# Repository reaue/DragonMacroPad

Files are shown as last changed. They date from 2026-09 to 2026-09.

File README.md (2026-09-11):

# DragonMacroPad

A macro pad with 8 switches, one rotary encoder, one OLED display and of course some RGB. It uses [QMK](https://qmk.fm/) firmware.

# CAD model

The full case and the pcb are connected by four M3x13mm screws and M3x5mx4mm heatset inserts, the inserts come under the `Top_case` and your screw the all macro pad by the bottom of the `Bottom_case`, like a sandwich with the pcb in the middle.

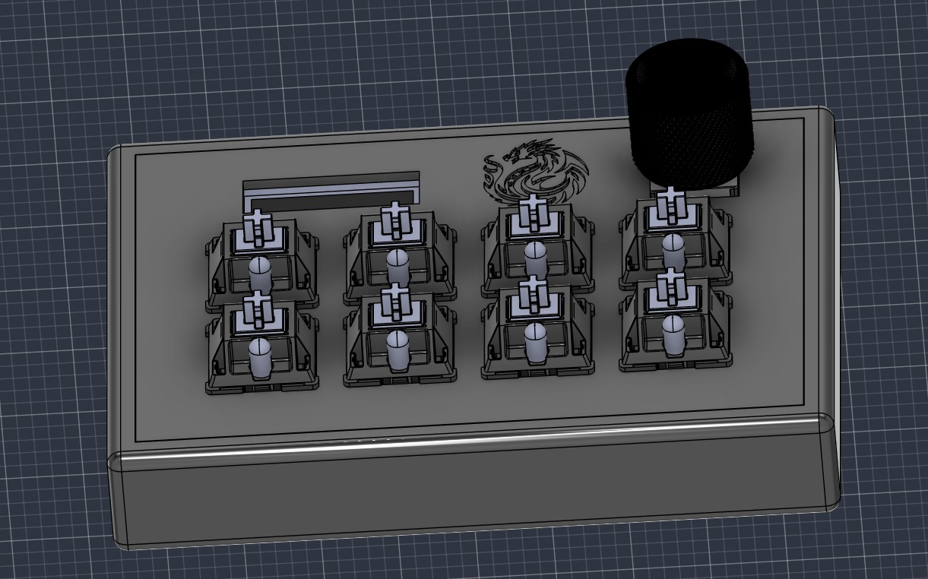
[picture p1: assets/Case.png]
Case


# Case parts

### Top_case

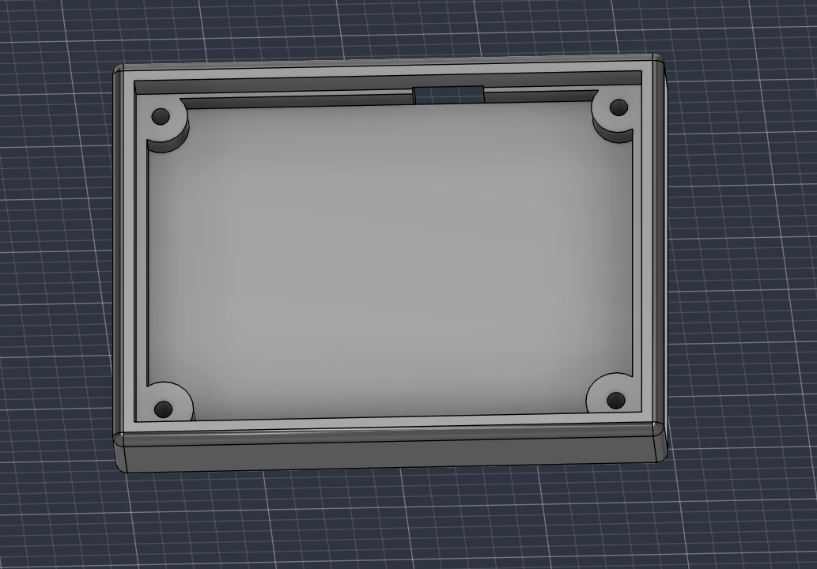
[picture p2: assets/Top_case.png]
Top_case


### Bottom_case

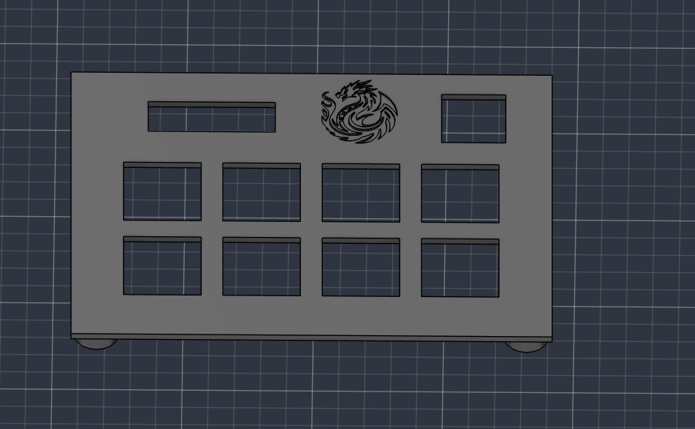
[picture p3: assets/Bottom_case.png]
Bottom_case


# PCB

### Schematic

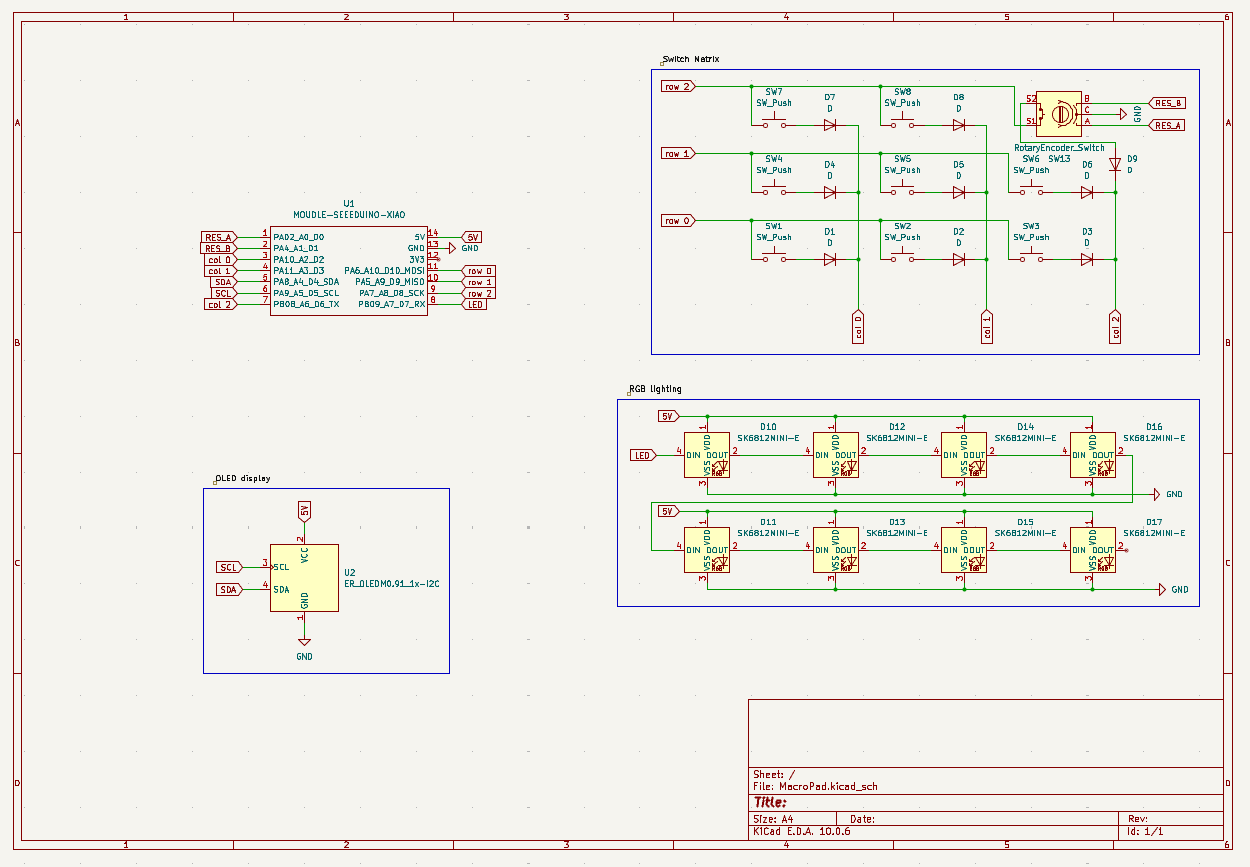
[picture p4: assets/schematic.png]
schematic


### PCB

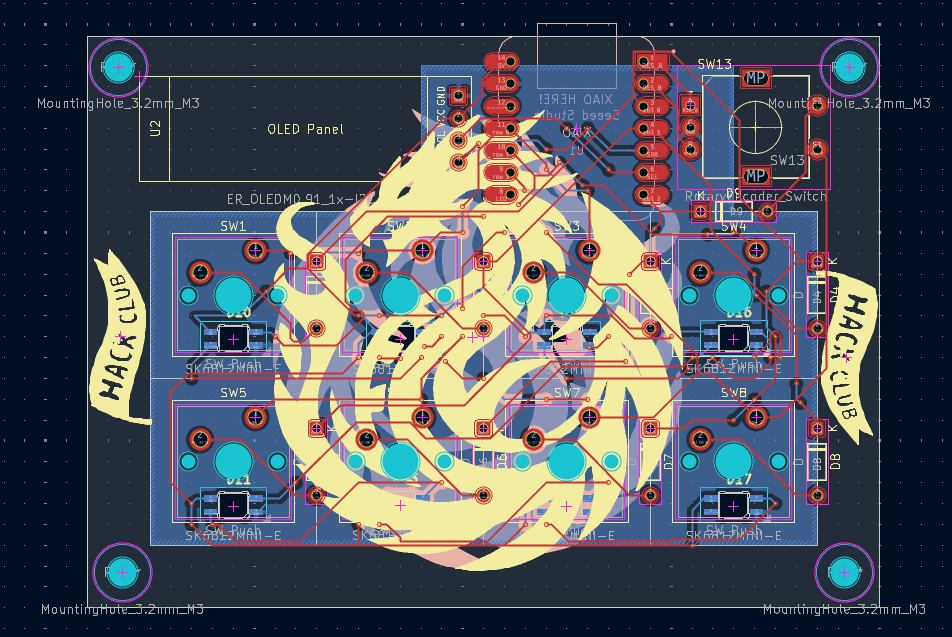
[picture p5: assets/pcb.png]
pcb


### The 3D model

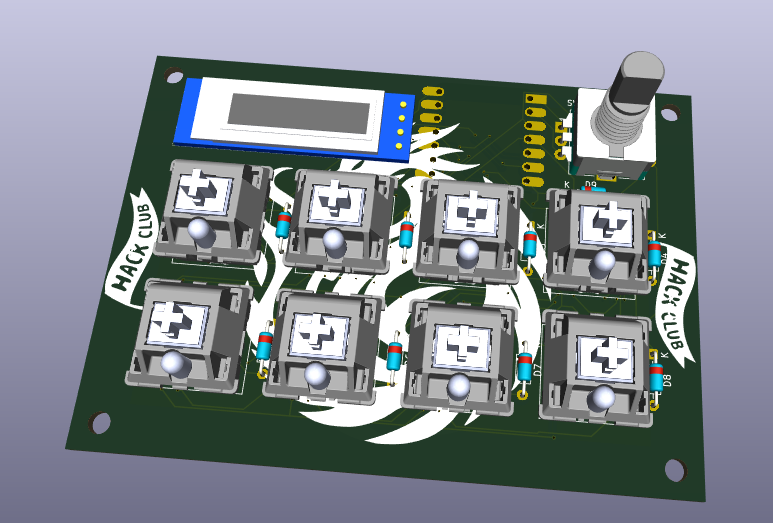
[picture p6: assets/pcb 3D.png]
PCB 3D


# Firmware

I use QMK for this DragonMacroPad.

Here, keys binding (in order, starting from the top right) :
- RGB Toggle
- RGB Mode Switch
- Previous Track
- Next Track
- Copy
- Paste
- Undo
- Redo

- The rotary encoder changes Volume and if it's press switch between Play/Pause.

# BOM

The real one is in the repo.

| Component | Quantity |
|---|---:|
| XIAO RP2040 | 1 |
| Cherry MX Switches | 8 |
| EC11 Rotary Encoder | 1 |
| WS2812 RGB LED | 8 |
| 0.91" 128x32 OLED Display | 1 |
| 1N4148 DO-35 Diodes | 9 |
| DSA Keycaps | 8 |
| PCB | 1 |
| M3x13mm | 4 |
| M3 M3x5x4 Heatset inserts | 4 |
| Case (2 printed parts )| 1 |
| EC11 Knob ( printed part )| 1 |

# Possible improvement

Take switches which are Led SMD compatible (such as Gateron SMD Yellow), because Cherry MX Switches do not let pass so much light.

# Credits

I used [QMK](https://qmk.fm/) and [Kicad](https://www.kicad.org/).
Moreover, I used one 3D model from [Ziemniaczenka](https://www.printables.com/@Ziemniaczenka)

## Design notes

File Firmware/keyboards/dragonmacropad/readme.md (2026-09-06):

# Firmware

**QMK**: This is a QMK firmware port of the dragonmacropad.

The firmware includes support for the 3×3 key matrix, rotary encoder, RGB LEDs and OLED display.

The compiled `.uf2` file is also included and ready to flash.

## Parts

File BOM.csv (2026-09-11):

Item name | Qty | Price (USD) | Item link | Note
XIAO RP2040 | 1 | 3.90 | https://www.seeedstudio.com/XIAO-RP2040-v1-0-p-5026.html
Cherry MX Switches | 8 | 21.99 | https://cherryxtrfy.com/keyboard-switches/cherry-mx-honey-switches/
EC Rotary Encoder | 1 | 1.61 | https://simbay.de/product/encoder-with-push-button/
WS2812 RGB Led | 8 | 0.90 | https://electropeak.com/ws2812b-5050-rgb-milky-smd
0.91 128x32 OLED Display | 1 | 2.90 | 0.91 128x32 OLED Display
1N4148 DO-35 Diodes | 9 | 0.94 | www.digikey.be/fr/products/detail/onsemi/1N4148/458603
DSA Keycaps | 8 | 6.85 | https://shop.beekeeb.com/products/dsa-1u-keycaps?variant=45012851425587&country=AT&currency=EUR
PCB printing | 1 | 4.00 | https://cart.jlcpcb.com/quote?stencilLayer=2&stencilWidth=100&stencilLength=100&stencilCounts=5&plateType=1
M3x13mm | 4 | 1.30 | https://eu.store.bambulab.com/fr/products/m3-flat-head-cap-machine-screws-fhcs?id=48691726909788&skr=yes
M3 M3x5x4 Heatset inserts | 4 | 6.25 | https://nl.aliexpress.com/item/4000232858343.html?gatewayAdapt=usa2nld4itemAdapt
Case (2 printed parts ) | 1 | 5.42 | https://www.prusa3d.com/fr/p/prusa-center/calculator
EC11 Knob ( printed part ) | 1 | 0.31 | https://www.prusa3d.com/fr/p/prusa-center/calculator

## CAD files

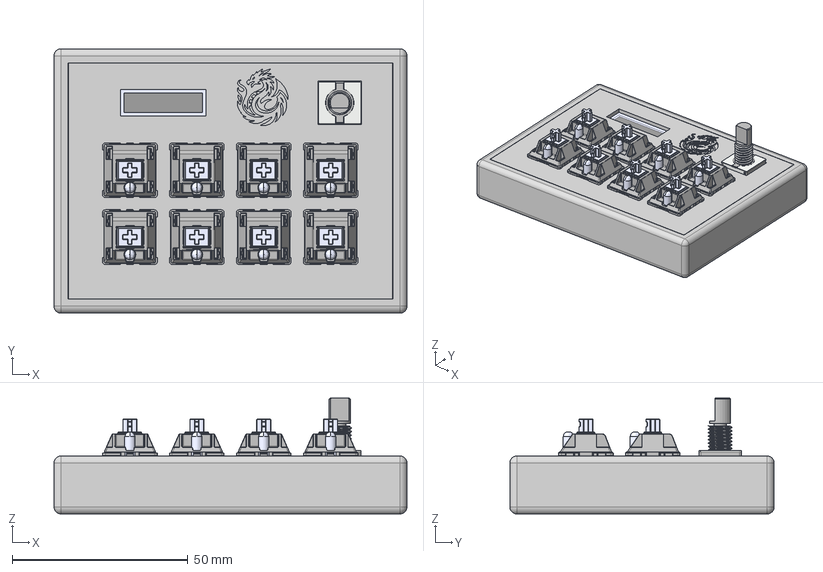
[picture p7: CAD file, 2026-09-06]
CAD/DragonMacroPad_case.step
100.5 x 75.3 x 33.0 mm
D_DO-35_SOD27_P7.62mm_Horizontal_1 x 9
MX Öá °´¼ü¡ä_¨¹ ___¡§1 x 8
MX ס סͥ¨¢¨¬_¡ §¡顧__ x 8
MXס ϞñLEDLEDLED x 8
MXÖá ÖáÌå µ×²¿ ¦Ì¡ Á2__Ä¬ÈÏ_¨¢2____¨¨_ x 8
֫½ğ__Ĭɏ__¨¨_ x 8
ѽת±ძǷ
type-c v2
smd_button v3
DOUT
DIN
VSS
VDD
smd_button v3(Mirror)
Pin1 x 8
Pin2 x 8
Pin3 x 8
Pin4 x 8
Mac834A_PCB

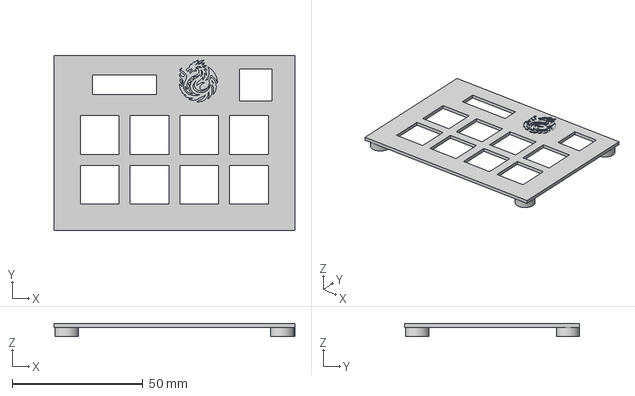
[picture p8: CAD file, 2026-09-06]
Production/Top_case.step
92.3 x 67.1 x 5.00 mm

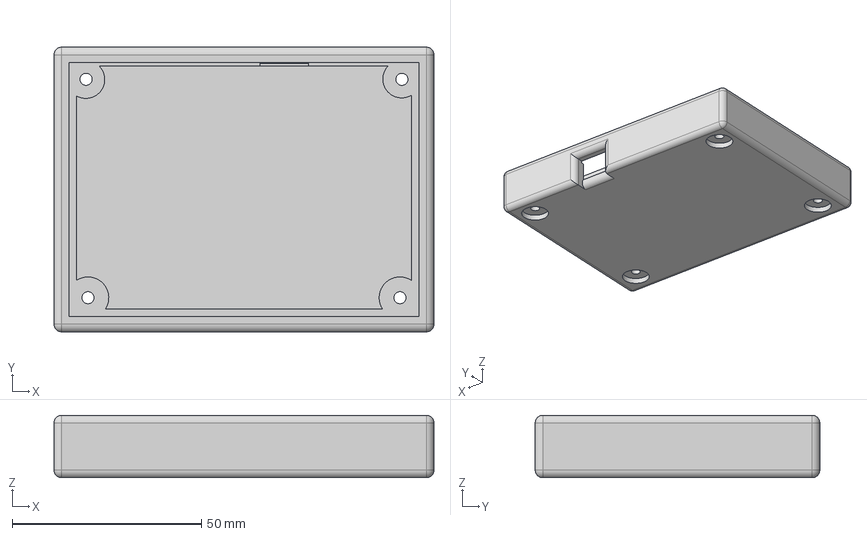
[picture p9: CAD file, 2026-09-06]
Production/Bottom_case.step
100.5 x 75.3 x 16.5 mm

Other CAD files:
Production/Encoder_knob.step

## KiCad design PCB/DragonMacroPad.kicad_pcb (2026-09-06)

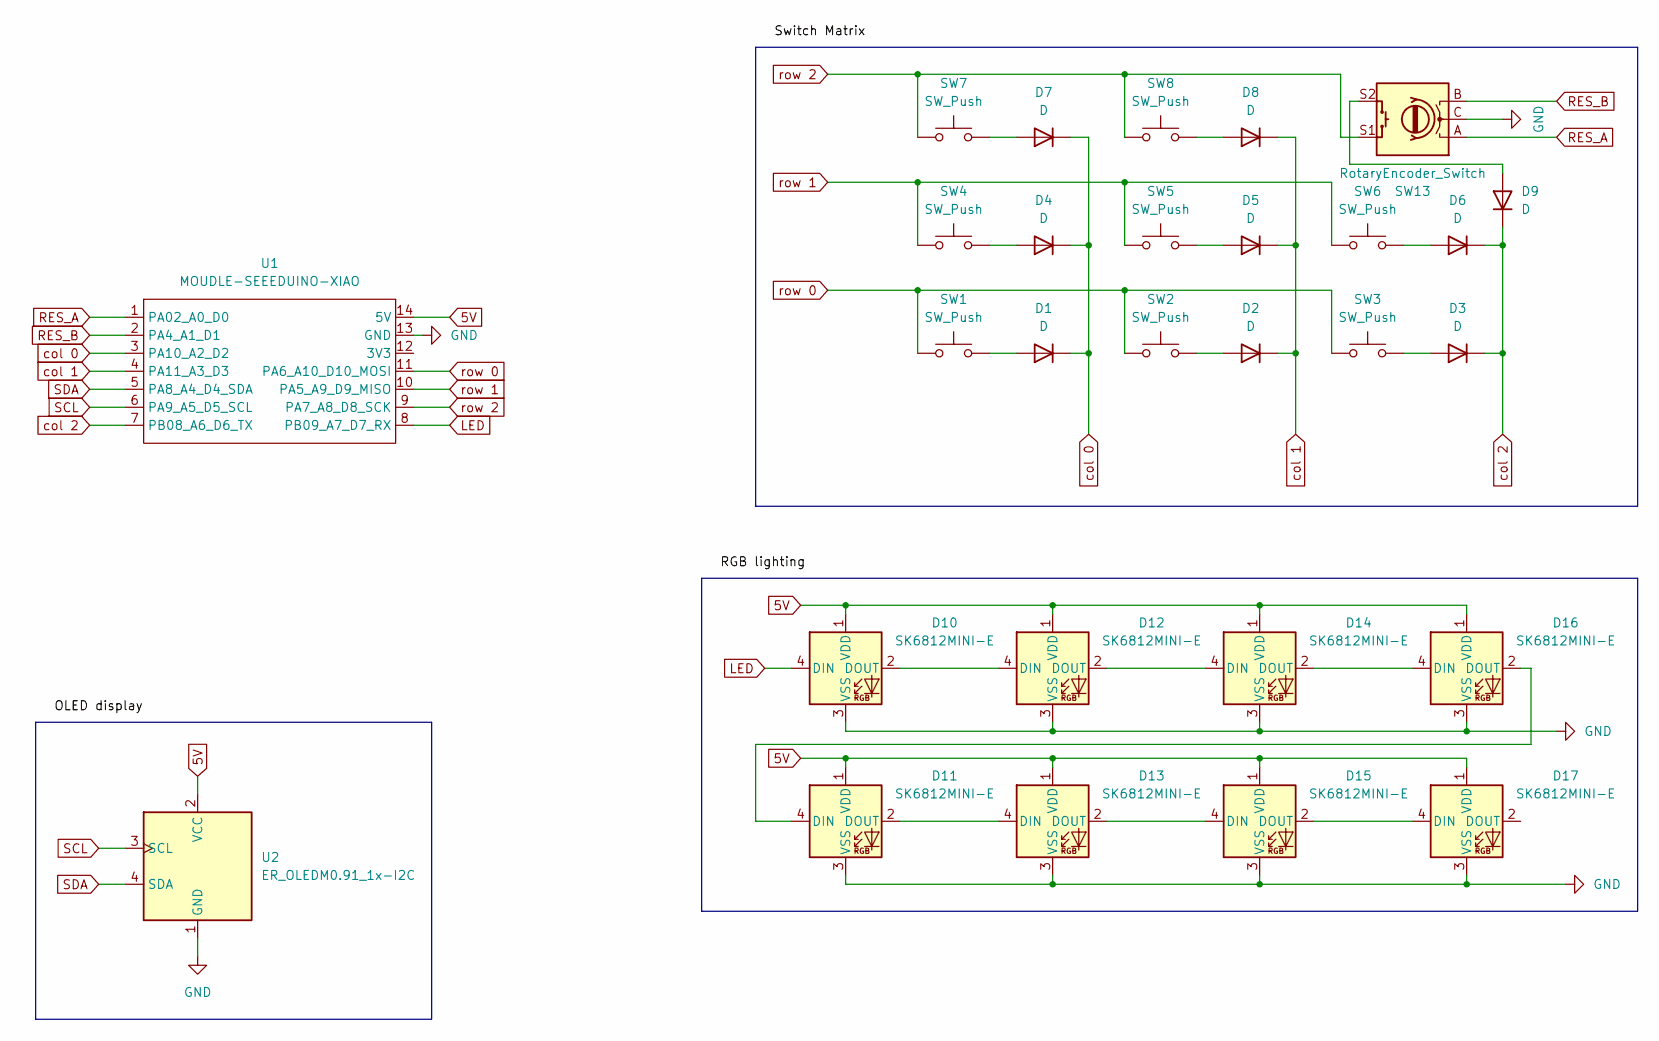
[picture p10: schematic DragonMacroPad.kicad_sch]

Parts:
D1, D2, D3, D4, D5, D6, D7, D8, D9: D; D_DO-35_SOD27_P7.62mm_Horizontal
D10, D11, D12, D13, D14, D15, D16, D17: SK6812MINI-E; SK6812MINI-E_fixed
SW1, SW2, SW3, SW4, SW5, SW6, SW7, SW8: SW_Push; SW_Cherry_MX_1.00u_PCB
SW13: RotaryEncoder_Switch; RotaryEncoder_Alps_EC11E-Switch_Vertical_H20mm
U1: MOUDLE-SEEEDUINO-XIAO; XIAO-Generic-Hybrid-14P-2.54-21X17.8MM
U2: ER_OLEDM0.91_1x-I2C; SSD1306-0.91-OLED-4pin-128x32

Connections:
5V: D10.1 (VDD), D11.1 (VDD), D12.1 (VDD), D13.1 (VDD), D14.1 (VDD), D15.1 (VDD), D16.1 (VDD), D17.1 (VDD), U1.14 (5V), U2.2 (VCC)
GND: D10.3 (VSS), D11.3 (VSS), D12.3 (VSS), D13.3 (VSS), D14.3 (VSS), D15.3 (VSS), D16.3 (VSS), D17.3 (VSS), SW13.C, U1.13 (GND), U2.1 (GND)
LED: D10.4 (DIN), U1.8 (PB09_A7_D7_RX)
unnamed: D1.2 (A), SW1.2
unnamed: D2.2 (A), SW2.2
unnamed: D3.2 (A), SW3.2
unnamed: D4.2 (A), SW4.2
unnamed: D5.2 (A), SW5.2
unnamed: D6.2 (A), SW6.2
unnamed: D7.2 (A), SW7.2
unnamed: D8.2 (A), SW8.2
unnamed: D9.2 (A), SW13.S2
unnamed: D10.2 (DOUT), D12.4 (DIN)
unnamed: D11.4 (DIN), D16.2 (DOUT)
unnamed: D11.2 (DOUT), D13.4 (DIN)
unnamed: D12.2 (DOUT), D14.4 (DIN)
unnamed: D13.2 (DOUT), D15.4 (DIN)
unnamed: D14.2 (DOUT), D16.4 (DIN)
unnamed: D15.2 (DOUT), D17.4 (DIN)
RES_A: SW13.A, U1.1 (PA02_A0_D0)
RES_B: SW13.B, U1.2 (PA4_A1_D1)
SCL: U1.6 (PA9_A5_D5_SCL), U2.3 (SCL)
SDA: U1.5 (PA8_A4_D4_SDA), U2.4 (SDA)
col 0: D1.1 (K), D4.1 (K), D7.1 (K), U1.3 (PA10_A2_D2)
col 1: D2.1 (K), D5.1 (K), D8.1 (K), U1.4 (PA11_A3_D3)
col 2: D3.1 (K), D6.1 (K), D9.1 (K), U1.7 (PB08_A6_D6_TX)
row 0: SW1.1, SW2.1, SW3.1, U1.11 (PA6_A10_D10_MOSI)
row 1: SW4.1, SW5.1, SW6.1, U1.10 (PA5_A9_D9_MISO)
row 2: SW7.1, SW8.1, SW13.S1, U1.9 (PA7_A8_D8_SCK)

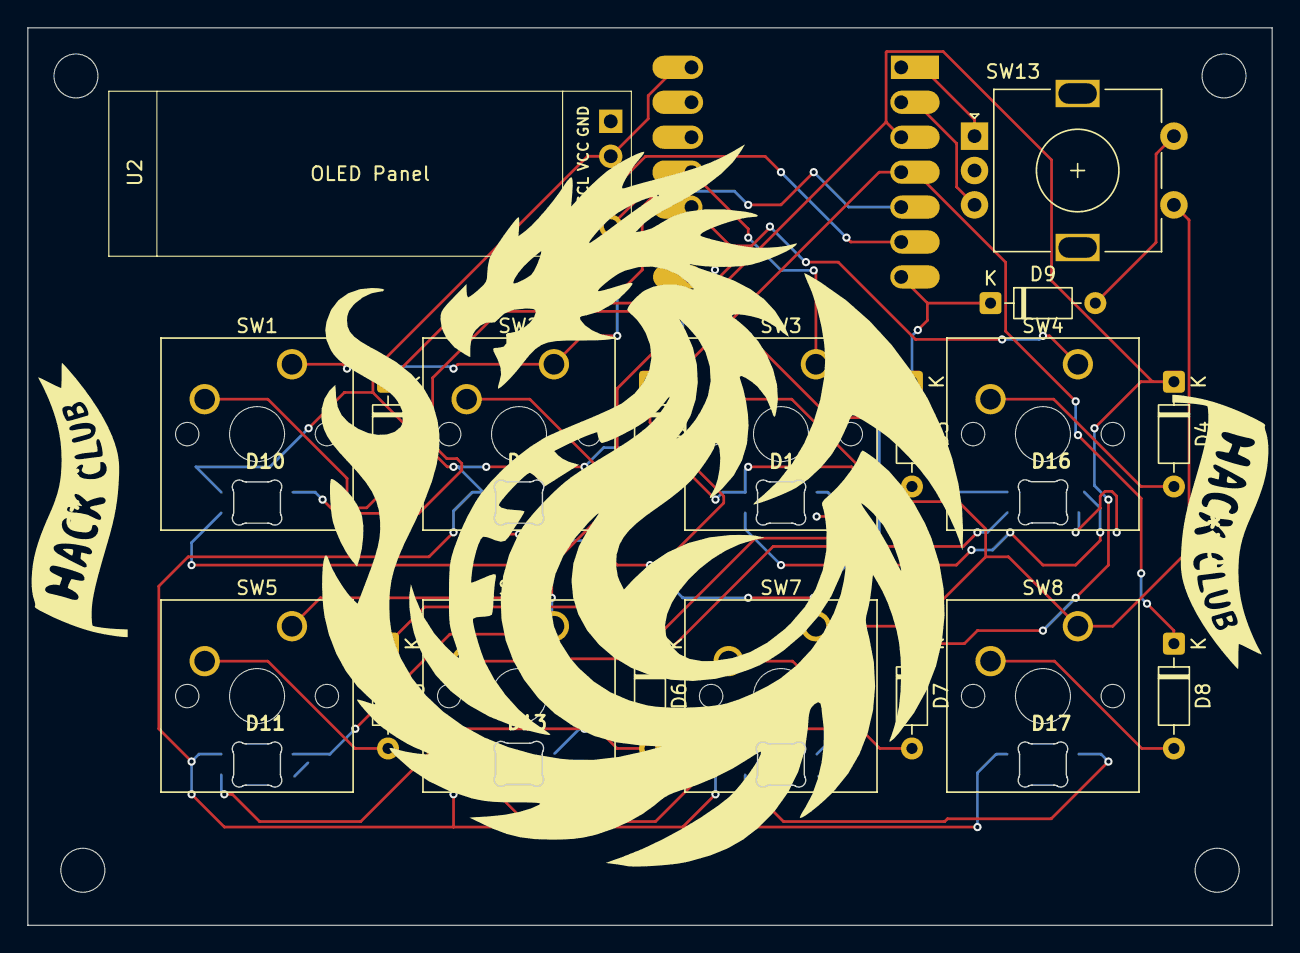
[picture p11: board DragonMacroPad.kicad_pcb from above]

Board: 2 copper layers, 90.5 x 65.3 mm, 28 parts (1 on the bottom side), 29 nets.

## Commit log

2026-09-06 Adding files
    [DragonMacroPad_case.step]
2026-09-06 Adding PCB files
    [DragonMacroPad.kicad_pcb, DragonMacroPad.kicad_sch, DragonMacroPad_case.step]
2026-09-06 Adding zip file for production
    [DragonMacroPad.kicad_pcb]
2026-09-06 adding file to the Production folder
    [Bottom_case.step, DragonMacroPad_case.step, Encoder_knob.step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]
2026-09-11 clean up
    [BOM.csv]
2026-09-11 quick fix
    [BOM.csv]
2026-09-11 finishing the BOM file
    [BOM.csv]
